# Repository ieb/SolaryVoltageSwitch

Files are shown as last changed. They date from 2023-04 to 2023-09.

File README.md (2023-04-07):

# Voltage Switch

Originally this code was written as a voltage switch for a lead acid batter, connected to a solar pannel, that would turn on when the voltage is high, and off when low. For years it powered a pond pump, but my wife got super annoyed by the large 12v battery in the flower bed.

This is 2023, and there are lithium batters.
Acer laptop battery packs are 11.1v at 7K Ah with a TI BQ4050 Lipo state of charge chip. The chip is on I2C so the code has 
been rewitten to use this chip basing the turn on and turn off points on the state of chage. On above 70% provided the solar volate is > 12V, and off when < 30% or if the solar volate drops below 11.5v (ie its dark)

The LED flashes once the pump is on and 2x when its off.

# Battery

I am using a 9x18650 Acer batter pack with a BMS controlled by a TI BQ4050 chip. (chip data sheet. https://www.ti.com/lit/ug/sluuaq3a/sluuaq3a.pdf)

The BMS is probably a cheap clone. With the packs feet on the ground looking at the pack the pins are

     |   | 1 | 2 | 3 | 4 | 5 | 6 | 7 | 8 |   |
     -----------------------------------------

1,2 BatV+
3   ID  - Currently not known
4   ID  - Currently purpose not known
5   SDA
6   SCL
7   0V
8   0V

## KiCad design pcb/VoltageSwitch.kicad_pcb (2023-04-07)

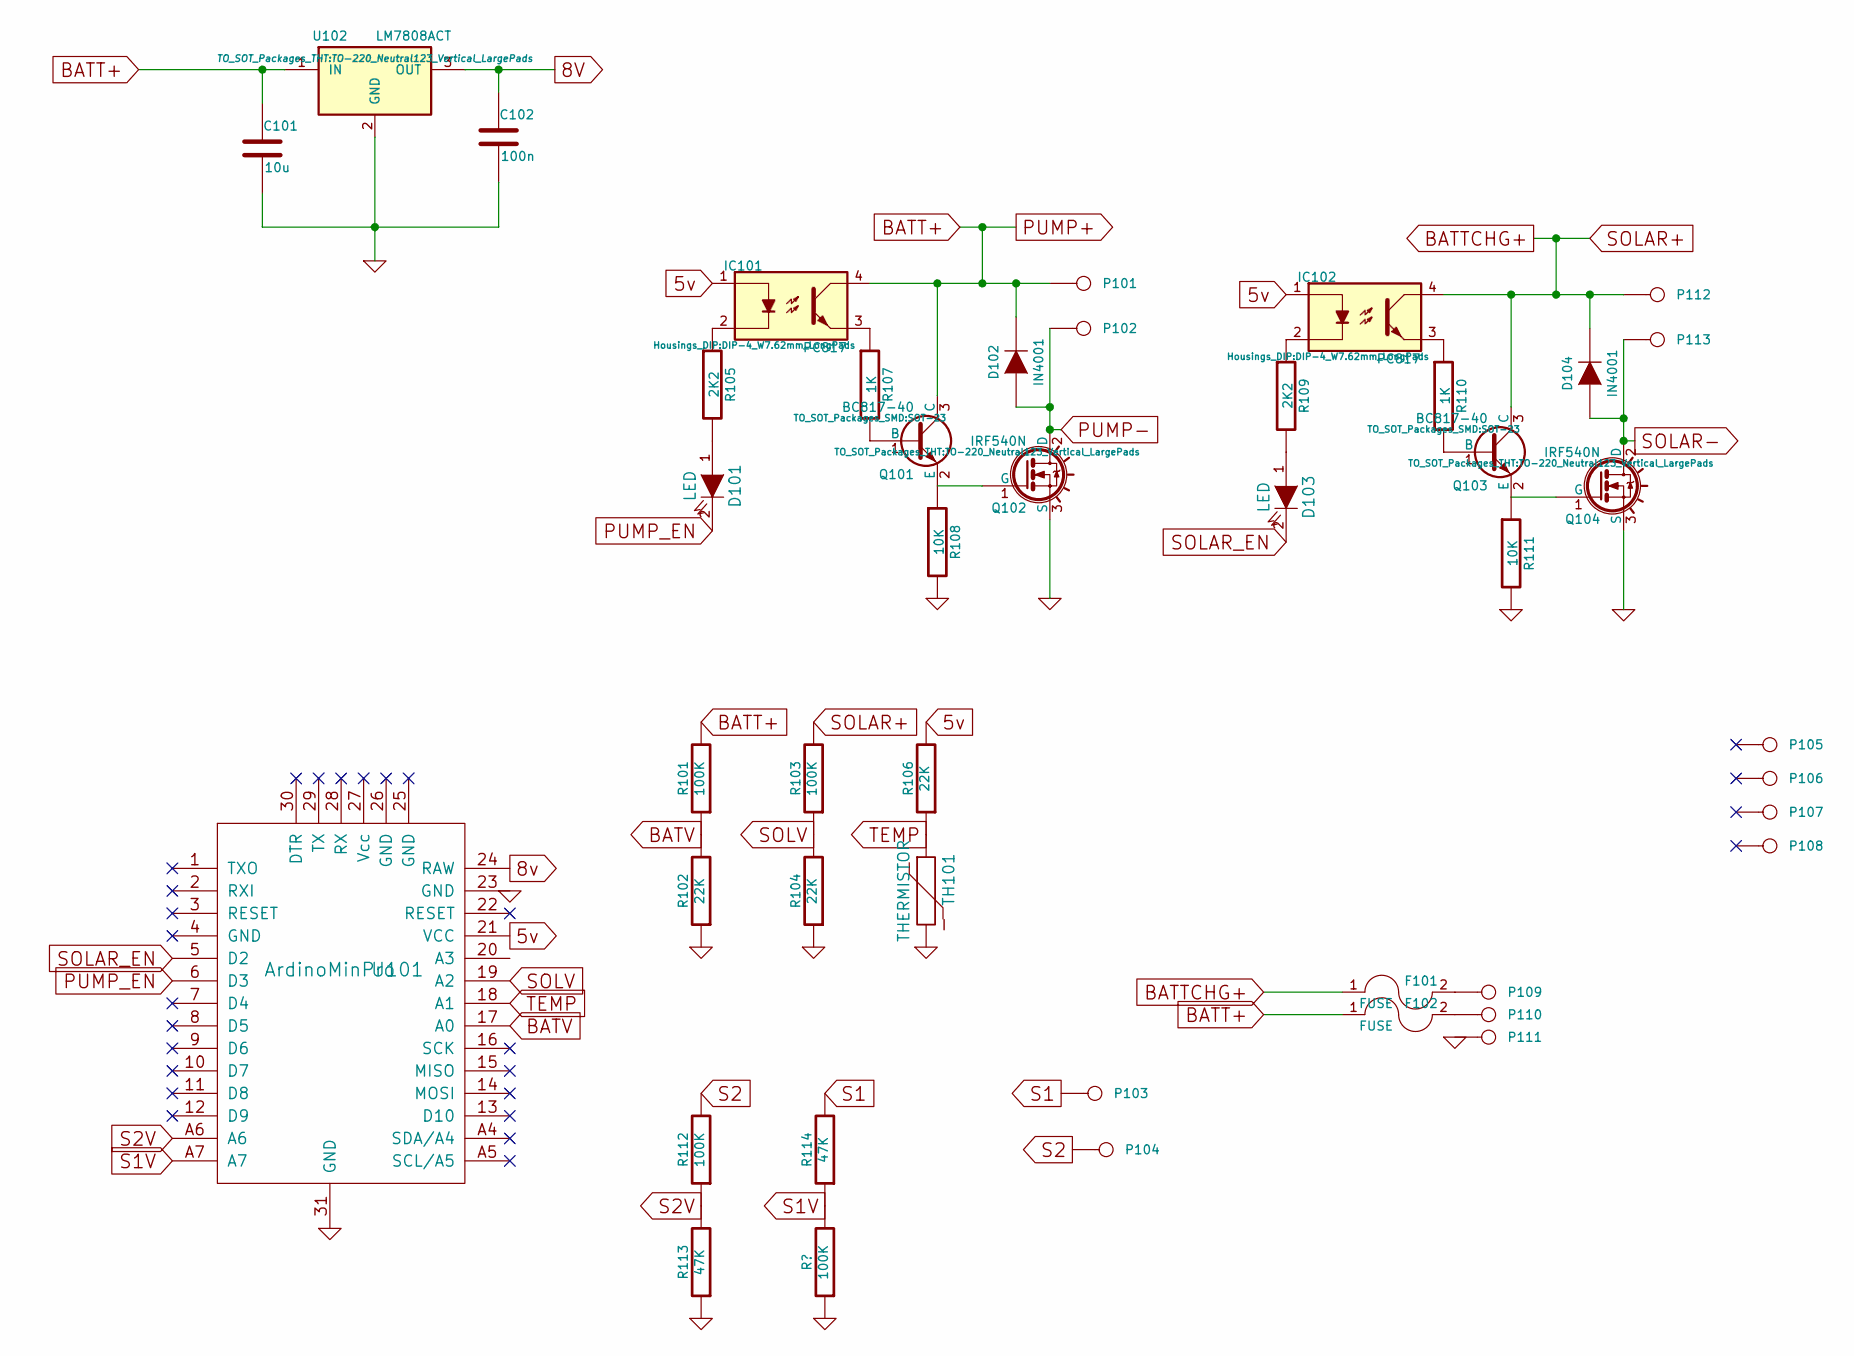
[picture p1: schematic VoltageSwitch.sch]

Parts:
C101: 10u; C_0805_HandSoldering
C102: 100n; C_0805_HandSoldering
D101, D103: LED; LED_0805
D102, D104: IN4001; D_0805
F101, F102: FUSE; BladeFuse-CarType
IC101, IC102: PC817; DIP-4_W7.62mm_LongPads
P101: Pump+; SolderWirePad_single_2mmDrill
P102: Pump-; SolderWirePad_single_2mmDrill
P103: S1; SolderWirePad_single_2mmDrill
P104: S2; SolderWirePad_single_2mmDrill
P105, P106, P107, P108: CONN_1; MountingHole_3.2mm_M3_ISO7380
P109: BatCharge+; SolderWirePad_single_2mmDrill
P110: BatTerm+; SolderWirePad_single_2mmDrill
P111: Bat-Term; SolderWirePad_single_2mmDrill
P112: Solar+; SolderWirePad_single_2mmDrill
P113: Solar-; SolderWirePad_single_2mmDrill
Q101, Q103: BC817-40; SOT-23
Q102, Q104: IRF540N; TO-220_Neutral123_Vertical_LargePads
R101, R103, R112: 100K; R_0805_HandSoldering
R102, R104, R106: 22K; R_0805_HandSoldering
R105, R109: 2K2; R_0805_HandSoldering
R107, R110: 1K; R_0805_HandSoldering
R108, R111: 10K; R_0805_HandSoldering
R113, R114: 47K; R_0805_HandSoldering
TH101: THERMISTOR; Resistor_Vertical_RM5mm
U101: ArdinoMinPro; ArduinoProMini
U102: LM7808ACT; TO-220_Neutral123_Vertical_LargePads

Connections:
5v: IC101.1, IC102.1, R106.2, U101.21 (VCC)
8V: C102.1, U101.24 (RAW), U102.3 (OUT)
BATT+: C101.1, D102.2 (K), F102.1, IC101.4, P101.1, Q101.3 (C), R101.2, U102.1 (IN)
BATTCHG+: D104.2 (K), F101.1, IC102.4, P112.1, Q103.3 (C), R103.2
BATV: R101.1, R102.2, U101.17 (A0)
GND: C101.2, C102.2, P111.1, Q102.3 (S), Q104.3 (S), R102.1, R104.1, R108.2, R111.2, R113.1, TH101.2, U101.23 (GND), U101.31 (GND), U102.2 (GND)
unnamed: D101.1 (A), R105.2
unnamed: D103.1 (A), R109.2
unnamed: F101.2, P109.1
unnamed: F102.2, P110.1
unnamed: IC101.2, R105.1
unnamed: IC101.3, R107.1
unnamed: IC102.2, R109.1
unnamed: IC102.3, R110.1
unnamed: Q101.1 (B), R107.2
unnamed: Q101.2 (E), Q102.1 (G), R108.1
unnamed: Q103.1 (B), R110.2
unnamed: Q103.2 (E), Q104.1 (G), R111.1
PUMP-: D102.1 (A), P102.1, Q102.2 (D)
PUMP_EN: D101.2 (K), U101.6 (D3)
S1: P103.1, R114.2
S1V: R114.1, U101.A7
S2: P104.1, R112.2
S2V: R112.1, R113.2, U101.A6
SOLAR-: D104.1 (A), P113.1, Q104.2 (D)
SOLAR_EN: D103.2 (K), U101.5 (D2)
SOLV: R103.1, R104.2, U101.19 (A2)
TEMP: R106.1, TH101.1, U101.18 (A1)

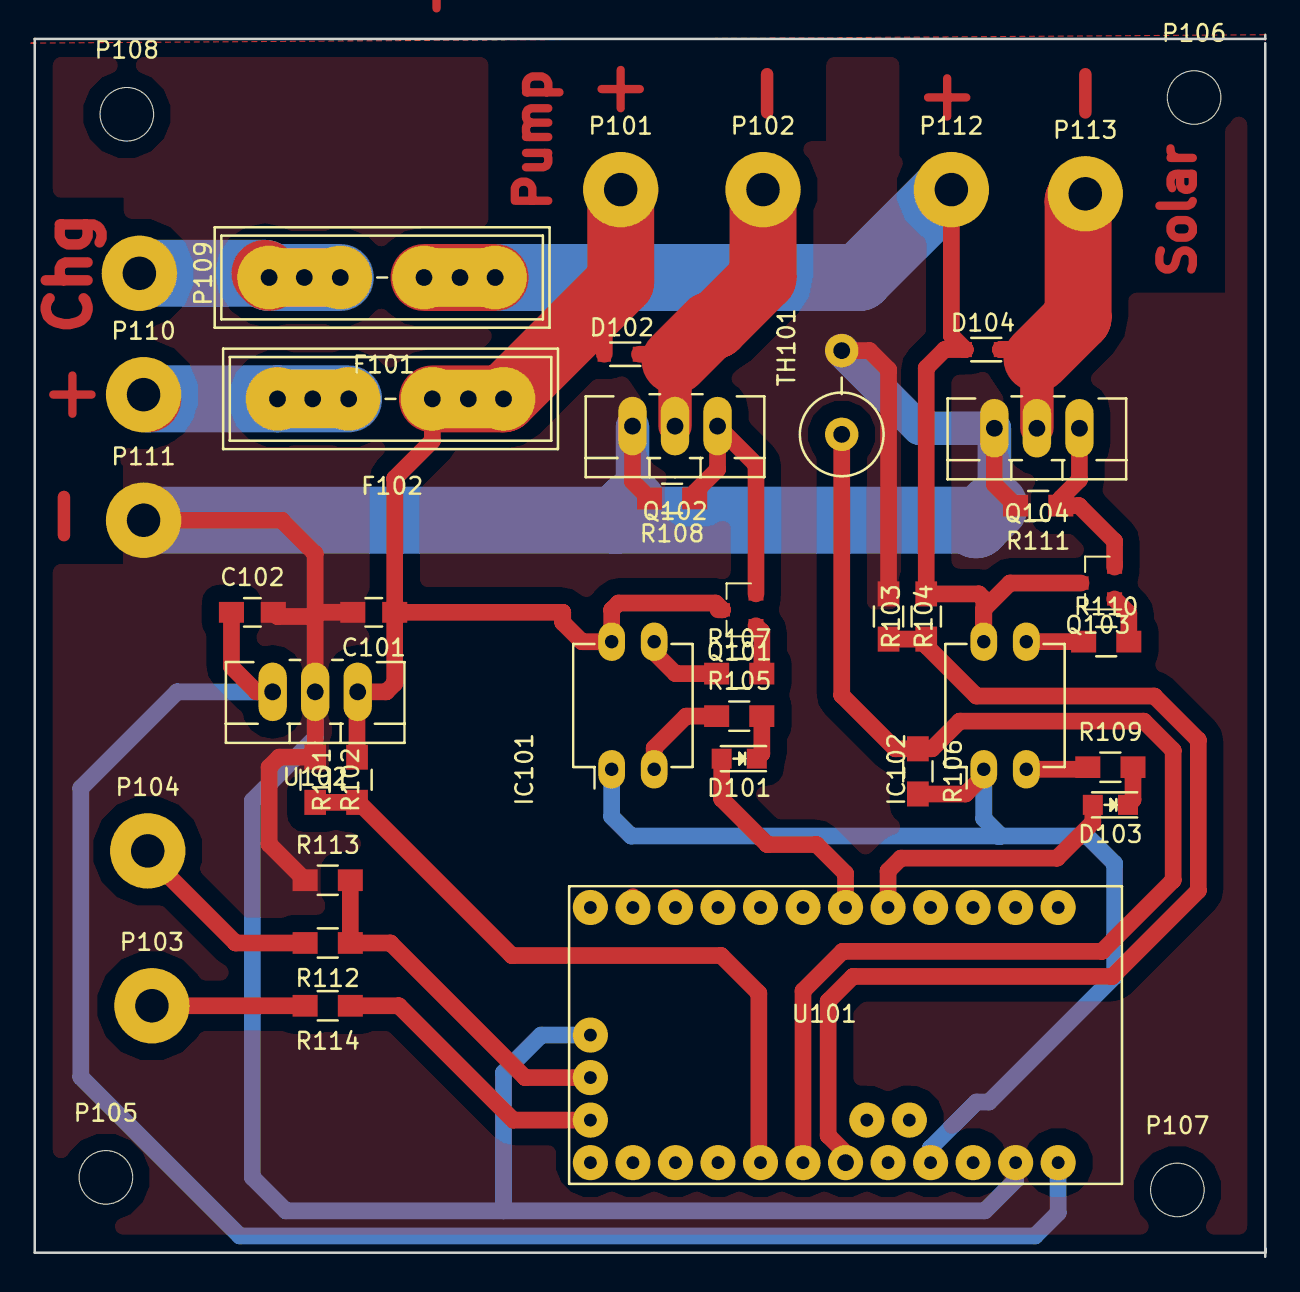
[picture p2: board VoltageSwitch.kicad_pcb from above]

Board: 2 copper layers, 73.5 x 73.0 mm, 44 parts (0 on the bottom side), 28 nets.

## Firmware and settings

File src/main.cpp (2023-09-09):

#include <Arduino.h>
#include <Wire.h>
#include "NtcSensor.h"



#define BATTERY_12V_ADC A0
#define BATTERY_8V_ADC A6
#define BATTERY_4V_ADC A7
#define TEMP_V_ADC A1
#define SOLAR_V_ADC A2
// Ignore the precision, its not relevant or valid, 
// Max voltage = 3.3*(top+bottom)/bottom
// mv/bit = (3.3/1024)*(top+bottom)/bottom
#define BATTERY_12V_SCALE 18.834778  // Top=100K/ Bottom=22 maxv=18.3 mv/bit= 17.87109375
// adjustment 17.87109375*12110/11491=18.833778201

#define BATTERY_8V_SCALE 10.521510       // Top=100K bottom=47 maxv = 10.3212765957, mv/bit = 10.0793716755
// adjustment 10.079371676*8070/7730.88=10.521509767
#define BATTERY_4V_SCALE 4.920638    // Top=46K Bottom=100K  direct    maxv = 6.1097826087, mv/bit = 5.9665845788
// adjustment 5.9665845788*4030/4886.63=4.92063771
#define SOLAR_SCALE 18.804355       // Top=100K/ Bottom=22 maxv=18.3 mv/bit= 17.87109375
// adjustment 17.87109375*12110/11508.98=18.804354974

#define SOLAR_EN 2
#define PUMP_EN 3

#define STANDBY 0
#define CHARGING 1
#define DISCHARGING 2

float adc4v, adc8v, packVoltage;
int16_t lightLevel = 500;


int chargeState = CHARGING;
int pumpEnable = HIGH;
int solarEnable = HIGH;

NtcSensor temperature(TEMP_V_ADC);




void showHelp() {
  Serial.println(F("Lipo voltage switch"));
  Serial.println(F("  - Send 'h' to show this message"));
  Serial.println(F("  - Send 's' to show status"));
  Serial.println(F("  - Send 'o' to toggle output"));
  Serial.println(F("  - Send 'c' to toggle charge"));
}

void heading(const __FlashStringHelper * txt) {
  Serial.print(txt);
  uint8_t l = 35 - strlen_P((const char*)txt);
  while(l> 0 ) {
    Serial.print(' ');
    l--;
  }
  Serial.print("");
}




void readSensors() {
  adc4v = BATTERY_4V_SCALE*analogRead(BATTERY_4V_ADC);
  delay(100);
  adc8v = BATTERY_8V_SCALE*analogRead(BATTERY_8V_ADC);
  delay(100);
  packVoltage = BATTERY_12V_SCALE*analogRead(BATTERY_12V_ADC);
  delay(100);
  lightLevel = analogRead(SOLAR_V_ADC);
  delay(100);
  temperature.update();
}


void showStatus() {
  readSensors();
  heading(F("Light Level"));Serial.println(lightLevel);
  heading(F("Pack Voltage (mv)"));Serial.println(packVoltage);
  heading(F("ADC 4v"));Serial.println(adc4v);
  heading(F("ADC 8v"));Serial.println(adc8v);
  heading(F("ADC 12v"));Serial.println(packVoltage);
  heading(F("Cell 1 (mv)"));Serial.println(adc4v);
  heading(F("Cell 2 (mv)"));Serial.println(adc8v-adc4v);
  heading(F("Cell 3 (mv)"));Serial.println(packVoltage-adc8v);
  heading(F("Temperature (C)"));Serial.println(temperature.getC());
  heading(F("Temperature (adc)"));Serial.println(temperature.getReading());
  heading(F("Pump"));Serial.println(pumpEnable?"Off":"On");
  heading(F("Charge"));Serial.println(solarEnable?"Off":"On");
}



void checkCommand() {
  if (Serial.available()) {
    char chr = Serial.read();
    switch ( chr ) {
      case 'h': showHelp(); break;
      case 's': showStatus(); break;
      case 'o': 
        pumpEnable = pumpEnable?LOW:HIGH;
        digitalWrite(PUMP_EN, pumpEnable);  
        break;
      case 'c': 
        solarEnable = solarEnable?LOW:HIGH;
        digitalWrite(SOLAR_EN, solarEnable); 
        break;
    }
  }
}


void setup() {
  Serial.begin(115200);
  pinMode(PUMP_EN, OUTPUT);
  digitalWrite(PUMP_EN, HIGH);
  pinMode(SOLAR_EN, OUTPUT);
  digitalWrite(SOLAR_EN, HIGH);
  showHelp();

}

bool checkOperatingConditions() {
  if ( temperature.getC() <= 4.0  ) {
    return false;
  } else if ( lightLevel > 50 ) { // to dark.
    return false;
  } else {
    return true;
  }
}



void loop() {
  static unsigned long lastUpdate = 0;
  checkCommand();
  unsigned long now = millis();
  if ( now -lastUpdate > 5000 ) {
    lastUpdate = now;
    readSensors();

      /*
      Battery state. 100% is 4.2v per cell.
      3.99 is 80%
      2.75 os 10%
      BMS will disconnect if the charge voltage goes too high, so 
      we probably dont really need to disconnect the solar.

      If the solar output is > 12.6 then the pump can be on regardless.
      Otherwise it depends on the battery state.
        If the battery is 4v per cell then pump should go on till the voltage drops to 3v/cell at which point it should 
        turn off
      */

    switch(chargeState) {
      case STANDBY:
        if ( checkOperatingConditions()  ) {
          chargeState = CHARGING;
          pumpEnable = HIGH;
          solarEnable = LOW;
          digitalWrite(PUMP_EN, pumpEnable);
          digitalWrite(SOLAR_EN, solarEnable);
          Serial.print(millis());
          Serial.println(F("Solar on "));
          showStatus();
        }
        break;
      case CHARGING:
        if ( !checkOperatingConditions() ) {
          chargeState = STANDBY;
          pumpEnable = HIGH;
          solarEnable = HIGH;
          digitalWrite(PUMP_EN, pumpEnable);
          digitalWrite(SOLAR_EN, solarEnable);
          Serial.print(millis());
          Serial.println(F("Too Cold or too dark"));
          showStatus();
        } else if (packVoltage >= 12000 ) {
          chargeState = DISCHARGING;
          pumpEnable = LOW;
          solarEnable = LOW;
          digitalWrite(PUMP_EN, pumpEnable);
          digitalWrite(SOLAR_EN, solarEnable);
          Serial.print(millis());
          Serial.println(F("Pump turned on "));
          showStatus();
        }
        break;
      case DISCHARGING:
        if ( !checkOperatingConditions() ) {
          chargeState = STANDBY;
          pumpEnable = HIGH;
          solarEnable = HIGH;
          digitalWrite(PUMP_EN, pumpEnable);
          digitalWrite(SOLAR_EN, solarEnable);
          Serial.print(millis());
          Serial.println(F("Too Cold or too dark"));
          showStatus();
        } else if (packVoltage <= 10500 ) {
          chargeState = CHARGING;
          pumpEnable = HIGH;
          solarEnable = LOW;
          digitalWrite(PUMP_EN, HIGH);
          digitalWrite(SOLAR_EN, LOW);
          Serial.print(millis());
          Serial.println(F("Pump turned off "));
          showStatus();
        }
        break;
    }      
    for(int i = 0; i < (chargeState+1); i++) {
      digitalWrite(13,HIGH);
      delay(100);
      digitalWrite(13,LOW);
      delay(100);
    }
  }
}

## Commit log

2023-03-24 Now using a Lipo batter pack and smb chip
2023-04-07 Mk2 operational
    [VoltageSwitch.kicad_pcb, VoltageSwitch.sch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]
